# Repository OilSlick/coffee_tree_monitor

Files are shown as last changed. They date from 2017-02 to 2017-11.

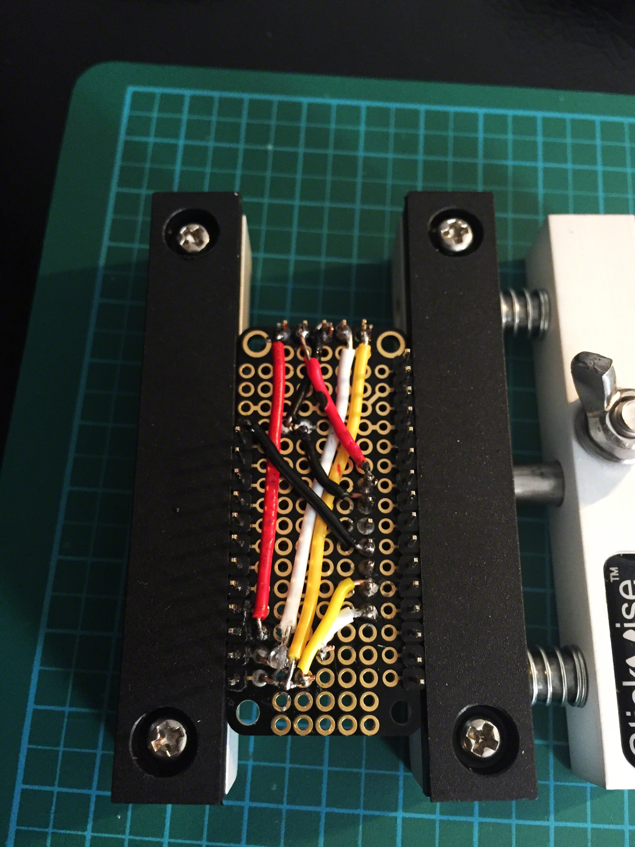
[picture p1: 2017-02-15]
images/proto-back.jpg

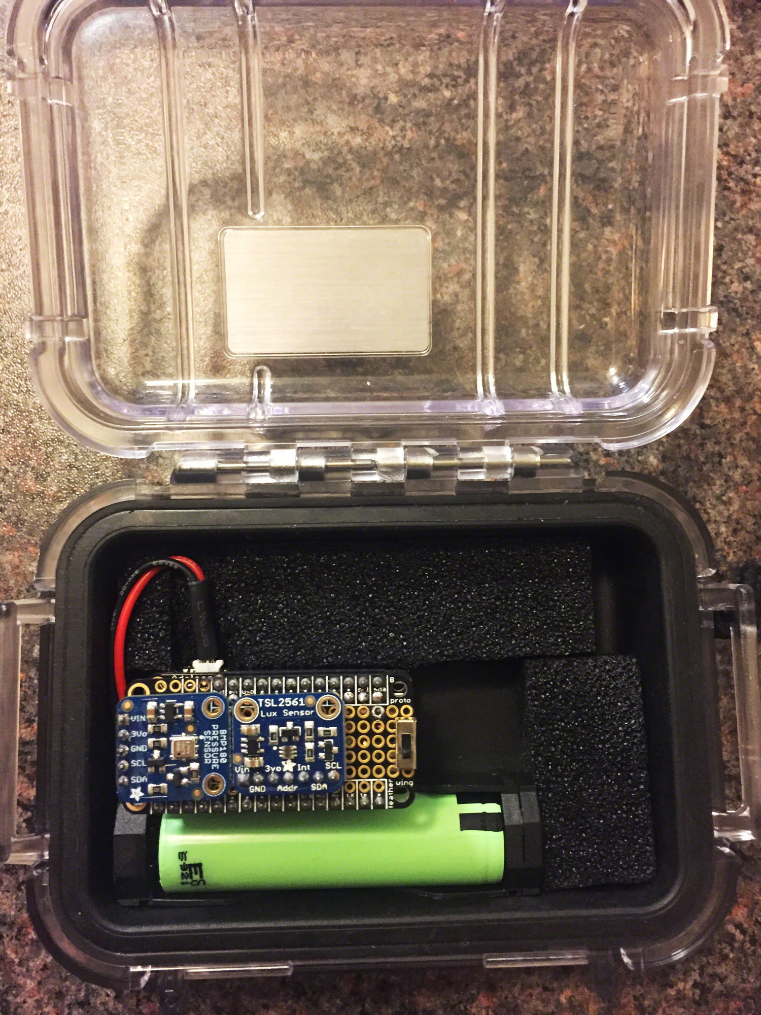
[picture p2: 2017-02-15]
images/sensor-case.jpg

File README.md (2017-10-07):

# Coffee Tree Monitor
An Arduino-based sensor network to monitor environmental conditions of coffee trees.

Intended to compare the differences between two types of microclimate for coffee trees; shaded and unshaded environments. 

### Basic Unit Operation

Collect the following data from each tree:

1. Amount of light
2. Air temperature
3. Soil moisture content 

**As of October 7, 2017 this project is still being developed.** I am currently prototyping the circuit and all of the sensors, which I'm still researching and sourcing.  

Current unit configurations and tests are being documented in the [wiki](https://github.com/OilSlick/coffee_tree_monitor/wiki)

### Hardware To-Do
* [x] Add SD Card adapter
* [ ] Add soil sensor
* [x] Add light sensor
* [x] Add solar panel 
* [x] Determine method for posting data online
* [ ] Organize circuit for project/gang box
* [ ] Evaluate battery life and consider physically smaller LiPo to replace current Li-ion battery

### Software To-Do
* [x] Configure for SD Card adapter
* [x] Add lowpower/sleep routines
* [x] Power down sensors between data collection ~~(this is causing problems with TSL2561)~~
* [ ] Configure Fona routines for data upload
* [ ] Add error handling and logging to SD, www, and via LED blink
  * [ ] ~~Add error on bmp.getTemperature~~
  * [x] Skip Adafruit IO conn attempt if wifi fails
  * [x] Fix failure to detect TSL2561 init fail
* [ ] Rotate log files

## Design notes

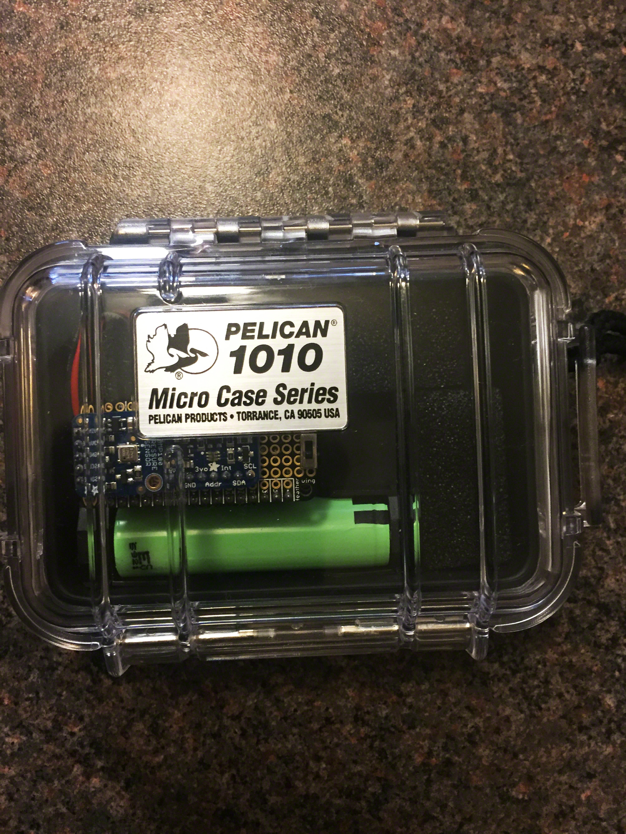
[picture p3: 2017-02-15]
images/sensor-case2.jpg

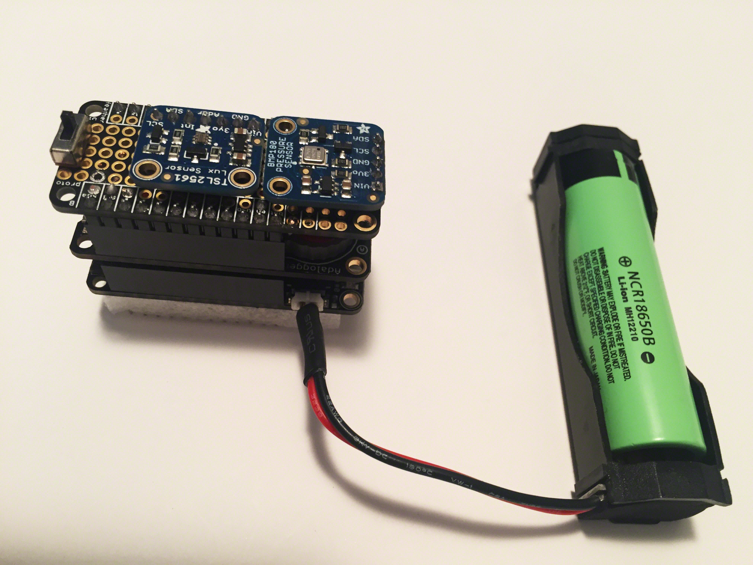
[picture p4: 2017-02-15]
images/sensor-batt2.jpg

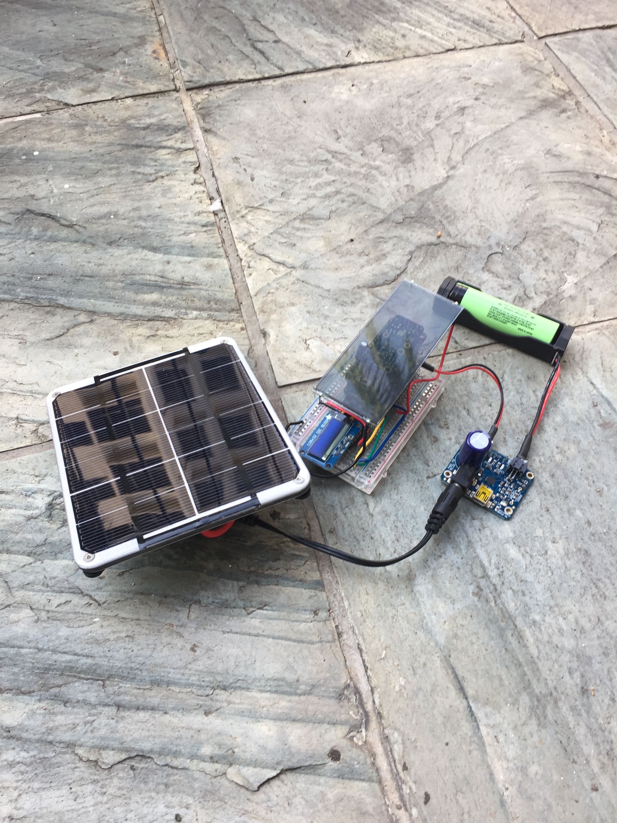
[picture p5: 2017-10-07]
images/solar-powered.jpg

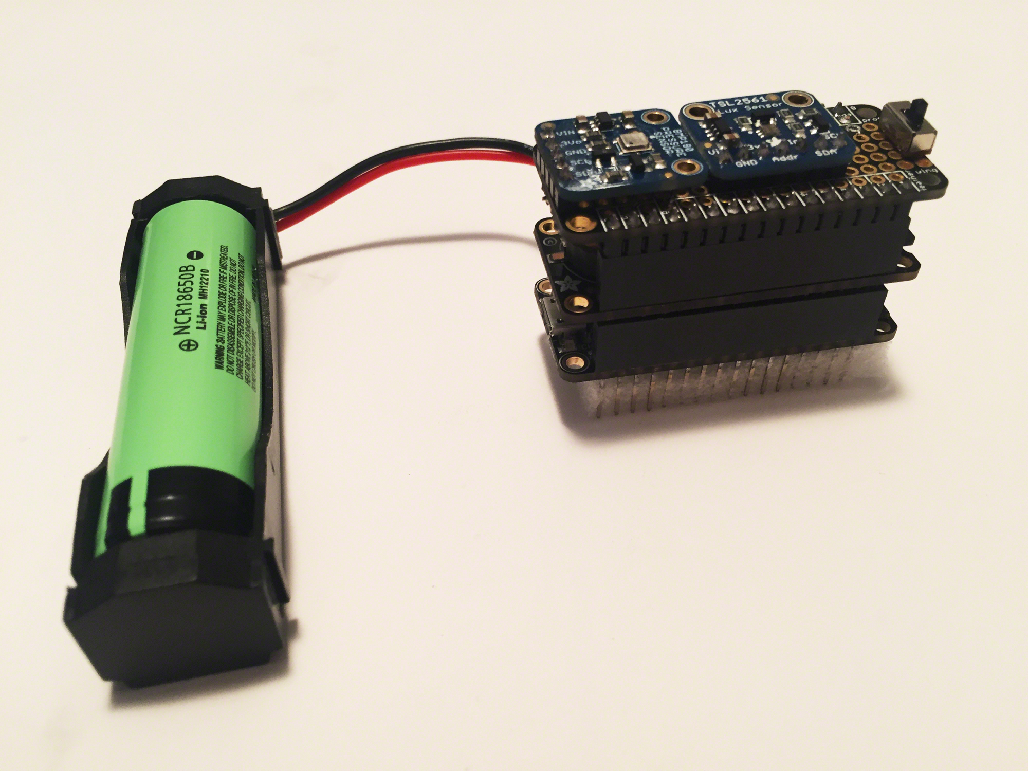
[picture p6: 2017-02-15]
images/sensor-batt.jpg

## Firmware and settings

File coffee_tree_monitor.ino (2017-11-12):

#include <Wire.h>                     //Needed for I2C 
#include <Adafruit_Sensor.h>          //Needed for both BMP180 and TSL2561
#include <SPI.h>                      //Needed for SD card adapter
#include <SD.h>                       //Needed for SD card adapter
#include "config.h"                   //Needed for Adafruit IO

//For OLED display
#include <Adafruit_GFX.h>
#include <Adafruit_SSD1306.h>
#define OLED_RESET 0
Adafruit_SSD1306 display(OLED_RESET);

/* I2C addresses:
   0x29  (41) TSL2561 Lux sensor
   0x3C       OLED Display
   0x68 (104) RTC
   0x77 (119) BMP180 Baro sensor
*/

String Statuses[] =  { "WL_IDLE_STATUS=0", "WL_NO_SSID_AVAIL=1", "WL_SCAN_COMPLETED=2", "WL_CONNECTED=3", "WL_CONNECT_FAILED=4", "WL_CONNECTION_LOST=5", "WL_DISCONNECTED=6"};
String TimeStamp = "";                //String to contain the timestamp for log files

const int SenorPowerPin = 2;          //Pin used to provide power to sensors
const int chipSelect = 15;            //CS pin for SD card adapter
const int lclvPin = 16;               //Controls the LCLV glass

const int TSL2561I2CAdd = 41;         //I2C address of TSL2561 (found using I2C sketch)
const int BMP180I2CAdd = 119;         //I2C address of BMP180 (found using I2C sketch)
bool IOconnERROR = 0;                 //Track connection failures
bool debug = 0;                       //Enable debugging with "1"
bool JustPrintRuntimeOnce = 0;        //Just give us one runtime reading
bool LCLVactive = 0;                  //Track if LCLV is on or off
int LCLVValue = 0;                    //Track LCLV value
float PressureVal = 0;                //Value returned by sensor
float TSL2561Val = 0;                 //Value returned by sensor
float TemperatureVal = 0;             //Value returned by sensor
bool BMP180Error = 0;                 //Track sensor errors
bool TSL2561Error = 0;                //Track sensor errors
bool SDError = 0;                     //Track SD adapter errors
bool WiFiError = 0;                   //Track WiFi connection error
byte I2Cerror;                        //Track I2C errors (when pinging individual addresses for up/down status)
int StartLoopRuntime;                 //Track loop run time (enabled with "debug = 1;" above)
int LoopRuntime;                      //Track loop run time (enabled with "debug = 1;" above)

int ThisSecond = 0;                   //Used to display on OLED for short duration
int DisplayDuration = ThisSecond + 10;  //Used to display on OLED for short duration

//For Adafruit IO
AdafruitIO_Feed *luxFeed = io.feed("Lux");
AdafruitIO_Feed *tempFeed = io.feed("Temp");
AdafruitIO_Feed *presFeed = io.feed("Pressure");
AdafruitIO_Feed *errorFeed = io.feed("Error");

//For SD card adapter
File DATALOG;
File ERRORLOG;
File LUXLOG;

//For BMP180 pressure, temp, altitude sensor
#include <Adafruit_BMP085_U.h>
Adafruit_BMP085_Unified bmp = Adafruit_BMP085_Unified(10085);

//For RTC
#include "RTClib.h"
RTC_PCF8523 rtc;

//For Lux sensor
#include <Adafruit_TSL2561_U.h>
Adafruit_TSL2561_Unified tsl = Adafruit_TSL2561_Unified(TSL2561_ADDR_LOW, 2561);

void setup()
{
  wdt_enable(WDTO_4S);  //Configure watchdog timer with 4-second timeout

  //For OLED display
  display.begin(SSD1306_SWITCHCAPVCC, 0x3C);  // initialize with the I2C addr 0x3C (for the 128x32)
  display.clearDisplay();
  display.display(); // NOTE: You _must_ call display after making any drawing commands

  rtc.begin();

  //Power on sensors early in loop
  pinMode(SenorPowerPin, OUTPUT);
  digitalWrite(SenorPowerPin, HIGH);

  pinMode(lclvPin, OUTPUT);
  analogWrite(lclvPin, 0);

  Serial.begin(115200);
  if ( debug == 1)
  {
    Serial.setDebugOutput(true);
    if ( Serial )
    {
      Serial.print("Debug enabled");
    }
  }

  Wire.begin();

  //For SD card adapter
  Serial.print("Initializing SD card...");
  pinMode(SS, OUTPUT);

  if (!SD.begin(chipSelect)) {
    Serial.println("SD card initialization failed");
    SDError = 1;
    //return;  //Need to better handle this error
  }
  else
  {
    Serial.println("SD card initialization done");
  }

  DATALOG = SD.open("log.txt", FILE_WRITE);
  // if the file opened, write header to it:
  if (DATALOG)
  {
    DATALOG.println("Date Time,Lux,Temp.C,Pressure.hPa");
    DATALOG.close();
  }
  else
  {
    // if the file didn't open, print an error to serial:
    if (Serial)
    {
      Serial.println("Error opening data log file");
    }
  }

  ERRORLOG = SD.open("error.txt", FILE_WRITE);
  // if the file opened, write header to it:
  if (ERRORLOG)
  {
    ERRORLOG.println("Date Time,Error");
    ERRORLOG.close();
  }
  else
  {
    // if the file didn't open, print an error:
    if (Serial)
    {
      Serial.println("Error opening error log file");
    }
  }

  //For BMP180
  if (Serial)
  {
    Serial.println("Initilizing Pressure Sensor"); Serial.println("");
  }

  /* Initialise the sensor */

  if (!bmp.begin())
  {
    /* There was a problem detecting the BMP085 ... check your connections */
    if (Serial)
    {
      Serial.println("No BMP180 detected ... Check your wiring or I2C address");
    }
    ERRORLOG = SD.open("error.txt", FILE_WRITE);
    if (ERRORLOG)
    {
      TimeStampSD(ERRORLOG);
      ERRORLOG.print("BMP180 is not responding");
      ERRORLOG.close();
    }
    BMP180Error = 1;
  }

  /* Display some basic information on this sensor */
  displayBMP180SensorDetails();

  //For TSL2561 sensor

  if (Serial)
  {
    Serial.println("Initilizing Light Sensor"); Serial.println("");
  }

  /* Initialise the sensor */

  Wire.beginTransmission(TSL2561I2CAdd);
  I2Cerror = Wire.endTransmission();
  if (Serial && debug == 1)
  {
    Serial.print("TSL2561 I2C error: ");
    Serial.println(I2Cerror);
  }
  if ( I2Cerror != 0 )  //Error "0" indicates a successful contact
  {
    if (Serial)
    {
      Serial.print("TSL2561 is not responding at address: ");
      Serial.print(TSL2561I2CAdd);
      Serial.print(" ("); Serial.print(TSL2561I2CAdd, HEX); Serial.println(")");
    }

    ERRORLOG = SD.open("error.txt", FILE_WRITE);
    if (ERRORLOG)
    {
      TimeStampSD(ERRORLOG);
      ERRORLOG.print("TSL2561 is not responding at address: ");
      ERRORLOG.print(TSL2561I2CAdd);
      ERRORLOG.print("(0x"); ERRORLOG.print(TSL2561I2CAdd, HEX); ERRORLOG.println(")");
      ERRORLOG.close();
      TSL2561Error = 1;
    }
  }

  if (!tsl.begin())
  {
    /* There was a problem detecting the TSL2561 ... check your connections */
    if (Serial)
    {
      Serial.println("No TSL2561 detected ... Check your wiring or I2C address");
    }
    TSL2561Error = 1;
  }

  /* Display some basic information on this sensor */
  displayTSL2561SensorDetails();

  /* Setup the sensor gain and integration time */
  configureSensor();

  //For RTC (must occur late in the loop)
  //Uncomment the line below to set the RTC
  if ( Serial )
  {
    //rtc.adjust(DateTime(F(__DATE__), F(__TIME__)));
  }

  //Connect to WiFi
  wdt_reset();
  Connect();

  //Connect to Adafruit IO
  if ( WiFiError == 0)
  {
    Serial.println("Connecting to Adafruit IO");
    // connect to io.adafruit.com
    // io.connect();
    // attach message handler for the each feed
    wdt_reset();
    luxFeed->onMessage(handleMessage);
    tempFeed->onMessage(handleMessage);
    presFeed->onMessage(handleMessage);
    errorFeed->onMessage(handleMessage);

    // wait for a connection
    int IOconnAttempt = 0;
    while (io.status() < AIO_CONNECTED && IOconnAttempt <= 60)
    {
      Serial.print(".");
      delay(500);
      IOconnAttempt++;
    }
    if ( IOconnAttempt > 60 )
    {
      IOconnERROR = 1;
      if ( Serial )
      {
        Serial.println("");
        Serial.println("Aborting connection attempt to Adafruit IO");
        Serial.print("IP address:   ");
        Serial.println(WiFi.localIP());
      }
      ERRORLOG = SD.open("error.txt", FILE_WRITE);
      if (ERRORLOG)
      {
        TimeStampSD(ERRORLOG);
        ERRORLOG.println("Adafruit IO connection failed");
        ERRORLOG.close();
      }
    }
    IOconnAttempt = 0;

    // we are connected
    if ( Serial );
    {
      Serial.println();
      Serial.println(io.statusText());
    }
  }
  if ( IOconnERROR == 0 && WiFiError == 0 && TSL2561Error == 0 && BMP180Error == 0 && SDError == 0 )
  {
    ERRORLOG = SD.open("error.txt", FILE_WRITE);
    TimeStampSD(ERRORLOG);
    ERRORLOG.println("REBOOT: OK");
    ERRORLOG.close();
    errorFeed->save("REBOOT: OK");
  }

  if ( IOconnERROR == 0 )
  {
    if ( BMP180Error == 1 )
    {
      errorFeed->save("REBOOT: BMP180 error");
    }
    if ( TSL2561Error == 1 )
    {
      errorFeed->save("REBOOT: TSL2561 error");
    }
    if ( SDError == 1 )
    {
      errorFeed->save("REBOOT: SD card error");
    }
  }

  LUXLOG = SD.open("luxlog.txt", FILE_WRITE);
  if (LUXLOG )
  {
    LUXLOG.println("Date Time,LCLV Raw,LCLV Modified,LCLV Value");
    LUXLOG.close();
  }

  if ( Serial )
  {
    /* We're ready to go! */
    Serial.println("Beginning data collection");
    //For OLED display
    display.clearDisplay();
    display.setTextSize(1);
    display.setTextColor(WHITE);
    display.setCursor(10, 0);
    display.print("Ready");
    display.display();    // NOTE: You _must_ call display after making any drawing commands
    delay(2500);
    display.clearDisplay();
    display.display();
  }
}

void loop()
{
  DateTime now = rtc.now();

  if ( debug == 1 )
  {
    StartLoopRuntime = millis();
    analogWrite(lclvPin, 1023);
    ReadTSL2561();
    //For OLED display
    display.clearDisplay();
    display.setTextSize(1);
    display.setTextColor(WHITE);
    display.setCursor(10, 0);
    display.print(TSL2561Val);
    display.display();    // NOTE: You _must_ call display after making any drawing commands
    /*LUXLOG = SD.open("luxlog.txt", FILE_WRITE);
      if (LUXLOG )
      {
      TimeStampSD(LUXLOG);
      LUXLOG.print(TSL2561Val);
      LUXLOG.print(",");
      LUXLOG.close();
      } */
    delay(2000);

    analogWrite(lclvPin, 511);
    ReadTSL2561();
    //For OLED display
    display.clearDisplay();
    display.setTextSize(1);
    display.setTextColor(WHITE);
    display.setCursor(10, 0);
    display.print(TSL2561Val);
    display.display();    // NOTE: You _must_ call display after making any drawing commands
    /*LUXLOG = SD.open("luxlog.txt", FILE_WRITE);
      if (LUXLOG )
      {
      TimeStampSD(LUXLOG);
      LUXLOG.print(TSL2561Val);
      LUXLOG.print(",");
      LUXLOG.close();
      }*/
    delay(2000);

    analogWrite(lclvPin, 0);
    ReadTSL2561();
    //For OLED display
    display.clearDisplay();
    display.setTextSize(1);
    display.setTextColor(WHITE);
    display.setCursor(0, 0);
    display.print(TSL2561Val);
    display.display();    // NOTE: You _must_ call display after making any drawing commands
    /*LUXLOG = SD.open("luxlog.txt", FILE_WRITE);
      if (LUXLOG )
      {
      LUXLOG.println(TSL2561Val);
      LUXLOG.close();
      }*/
    //delay(2000);
  }

  //Clear display after 15s
  if ( now.second() >= DisplayDuration )
  {
    display.clearDisplay();
    display.display();
  }
  // io.run(); keeps the client connected to
  // io.adafruit.com, and processes any incoming data.
  if ( WiFiError == 0 && IOconnERROR == 0 )
  {
    io.run();
  }

  if ( now.second() == 0 ) //Update SD log file every minute
  {
    if ( LCLVactive == 1 )
    {
      //shut off LCLV to get good read on LUX
      analogWrite(lclvPin, 0);
      LCLVactive = 0;
    }
    if ( BMP180Error == 0 )
    {
      ReadBMP180();
    }
    if ( TSL2561Error == 0 )
    {
      ReadTSL2561();
    }
    LUXLOG = SD.open("luxlog.txt", FILE_WRITE);
    if (LUXLOG )
    {
      TimeStampSD(LUXLOG);
      LUXLOG.print(TSL2561Val);
      LUXLOG.print(",");
      LUXLOG.close();
    }
    // If lux is nearing saturation, utlize LCLV and take a new reading
    if ( TSL2561Val >= 10000 )
    {
      LCLVValue = 859;  //LCLV at 859; 84% of 3v which is 50% at 5v, the voltage of LCLV
      analogWrite(lclvPin, LCLVValue);
      LCLVactive = 1;
      ReadTSL2561();
      analogWrite(lclvPin, 0); //Turn off LCLV to save juice
      LCLVactive = 0;
      LUXLOG = SD.open("luxlog.txt", FILE_WRITE);
      if (LUXLOG )
      {
        LUXLOG.print(TSL2561Val);
        LUXLOG.print(",");
        LUXLOG.println(LCLVValue);
        LUXLOG.close();
      }
    }
    else
    {
      LUXLOG = SD.open("luxlog.txt", FILE_WRITE);
      if (LUXLOG )
      {
        LUXLOG.print("0");
        LUXLOG.print(",");
        LUXLOG.println("0");
        LUXLOG.close();
      }
    }
    if ( Serial )
    {
      Serial.print(now.hour(), DEC);
      Serial.print(":");
      Serial.print(now.minute(), DEC);
      Serial.print(":");
      Serial.println(now.second(), DEC);
      WriteBMP180Serial();
      WriteTSL2561Serial();
      ThisSecond = now.second();
      DisplayDuration = ThisSecond + 15;
      WriteBMP180OLED();
      WriteTSL2561OLED();
      display.setTextSize(1); //textsize 1 = 7 px high
      display.setTextColor(WHITE);
      display.setCursor(50, 24);
      display.print(now.hour(), DEC);
      display.print(":");
      display.print(now.minute(), DEC);
      display.print(":");
      display.println(now.second(), DEC);
      display.display();
    }
    DATALOG = SD.open("log.txt", FILE_WRITE);
    // if the file opened okay, write to it:
    if (DATALOG)
    {
      TimeStampSD(DATALOG);
      if ( TSL2561Error == 0 )
      {
        WriteTSL2561SD();
      }
      if ( BMP180Error == 0 )
      {
        WriteBMP180SD();
      }
      DATALOG.println();
      DATALOG.close();
    }
    else
    {
      // if the file didn't open, print an error:
      Serial.println("error opening log file");
    }
    if (WiFiError == 0 && IOconnERROR == 0 )
    {
      if ( BMP180Error == 0 )
      {
        wdt_reset();
        WriteBMP180IO();
      }
      if ( TSL2561Error == 0 )
      {
        wdt_reset();
        WriteTSL2561IO();
      }
    }
    else
    {
      if ( Serial )
      {
        Serial.println("Not attempting write to Adafruit IO (IOConnERROR = 1)");
      }
    }
  }

  if ( debug == 1)
  {
    if ( now.second() == 0 || now.second() == 30 && JustPrintRuntimeOnce == 0 )
    {
      LoopRuntime = (millis() - StartLoopRuntime);
      Serial.print("Loop runtime: "); Serial.print(LoopRuntime); Serial.println(" ms");
      JustPrintRuntimeOnce = 1;
    }
    else
    {
      JustPrintRuntimeOnce == 0;
    }
  }
}

void TimeStampSD(File LogFile)  //Requires the name of the logfile to be passed, i.e. TimeStampSD(ERRORLOG);
{
  DateTime now = rtc.now();

  String theyear = String(now.year(), DEC);
  String themonth = String(now.month(), DEC);
  String theday = String(now.day(), DEC);
  String thehour = String(now.hour(), DEC);
  String themin = String(now.minute(), DEC);
  //Put all the time and date strings into one String
  TimeStamp = String(theyear + "/" + themonth + "/" + theday + " " + thehour + ":" + themin + ",");

  LogFile.print(TimeStamp);
}

void Connect()
{
  if ( WiFiError == 0 )
  {
    if (Serial)
    {
      Serial.print("Connecting to ");
      Serial.println(WIFI_SSID);
    }

    if (WiFi.status() != WL_CONNECTED)
    {
      WiFi.begin(WIFI_SSID, WIFI_PASS);
      int Attempt = 0;
      while (WiFi.status() != WL_CONNECTED)
      {
        delay(500);
        Attempt++;
        Serial.print(".");
        if (Attempt == 60)
        {
          if (Serial)
          {
            Serial.println();
            Serial.println("WiFi connection failed");
          }
          ERRORLOG = SD.open("error.txt", FILE_WRITE);
          if (ERRORLOG)
          {
            TimeStampSD(ERRORLOG);
            ERRORLOG.println("WiFi connection failed");
            ERRORLOG.close();
          }
          WiFiError = 1;
          IOconnERROR = 1; //If no WiFi connection, prevent connection to Adafruit IO
          return;
        }
      }
    }
    Serial.println("");
    Serial.println("WiFi connected");
    Serial.print("IP address: ");
    Serial.println(WiFi.localIP());
  }
}

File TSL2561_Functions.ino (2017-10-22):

void displayTSL2561SensorDetails(void)
{
  sensor_t sensor;
  tsl.getSensor(&sensor);
  Serial.println("------------------------------------");
  Serial.print  ("Sensor:       "); Serial.println(sensor.name);
  Serial.print  ("Driver Ver:   "); Serial.println(sensor.version);
  Serial.print  ("Unique ID:    "); Serial.println(sensor.sensor_id);
  Serial.print  ("Max Value:    "); Serial.print(sensor.max_value); Serial.println(" lux");
  Serial.print  ("Min Value:    "); Serial.print(sensor.min_value); Serial.println(" lux");
  Serial.print  ("Resolution:   "); Serial.print(sensor.resolution); Serial.println(" lux");  
  Serial.println("------------------------------------");
  delay(500);
}

/**************************************************************************/
/*
    Configures the gain and integration time for the TSL2561
*/
/**************************************************************************/
void configureSensor(void)
{
  /* You can also manually set the gain or enable auto-gain support */
   tsl.setGain(TSL2561_GAIN_1X);      /* No gain ... use in bright light to avoid sensor saturation */
  // tsl.setGain(TSL2561_GAIN_16X);     /* 16x gain ... use in low light to boost sensitivity */
  // tsl.enableAutoRange(true);            /* Auto-gain ... switches automatically between 1x and 16x */
  
  /* Changing the integration time gives you better sensor resolution (402ms = 16-bit data) */
  // tsl.setIntegrationTime(TSL2561_INTEGRATIONTIME_13MS);      /* fast but low resolution */
  // tsl.setIntegrationTime(TSL2561_INTEGRATIONTIME_101MS);  /* medium resolution and speed   */
   tsl.setIntegrationTime(TSL2561_INTEGRATIONTIME_402MS);  /* 16-bit data but slowest conversions */

  /* Update these values depending on what you've set above! 
  Serial.print  ("Gain:         "); Serial.println("Auto");
  Serial.print  ("Timing:       "); Serial.println("402 ms");
  Serial.println("------------------------------------"); */
}

void ReadTSL2561()
{
  /* Get a new sensor event */ 
  sensors_event_t event;
  tsl.getEvent(&event);   //TSL2561 Lux sensor
  
  /* Display the results (light is measured in lux) */
  if (event.light)
  {
    TSL2561Val = event.light;
    if ( TSL2561Val >= 17000 )
    {
      errorFeed->save("TSL2561 sensor saturated");  //Log error to Adafruit IO
      ERRORLOG = SD.open("error.txt", FILE_WRITE);
      if (ERRORLOG)
    {
      TimeStampSD(ERRORLOG);
      ERRORLOG.println("TSL2561 Sensor Error: lux above sensor max threshold");
      ERRORLOG.close();
    }
    }
  }
  else
  {
    /* If event.light = 0 lux during sun-down, there is likely not enough light for the sensor to read */
    TSL2561Val = 0;
  }  
}

void WriteTSL2561Serial()
{
  Serial.print("Lux:         ");
  Serial.print(TSL2561Val);
  Serial.println(" Lux");
}

void WriteTSL2561SD()
{
  DATALOG.print(TSL2561Val);
  DATALOG.print(",");
}

void WriteTSL2561IO()
{
  luxFeed->save(TSL2561Val);
}

void WriteTSL2561OLED()
{
  display.setTextSize(1); //textsize 1 = 7 px high
  display.setTextColor(WHITE);
  display.setCursor(0,16);
  display.print("Lux:      ");
  display.print(TSL2561Val);
  display.println(" Lux");
  display.display();    // NOTE: You _must_ call display after making any drawing commands
}

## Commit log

2017-01-26 Updated docs
    [coffee_tree_monitor.fzz]
2017-02-02 Several changes
    including low power implementation and SD card utilization (memory hog).
    [coffee_tree_monitor.fzz]
2017-02-03 Added delays around TSL2561 re-inits
    Adding 500ms delays after power-up and again after re-initialization
    and configuration seem to correct the issue with incorrect lux readings
    after powering off the sensor.
    [TSL2561_Functions.ino, coffee_tree_monitor.ino]
2017-02-03 Blink onboard LED to signal end of startup
2017-02-03 Updated to include SD adapter
    [coffee_tree_monitor.fzz]
2017-02-07 Updated schematics and a test sketch
    [coffee_tree_monitor.fzz]
2017-02-08 Update files with huzzah code
    Archived sketches based on the Fona and replaced with current sketches
    based on the Huzzah
    [BMP180_Functions.ino, TSL2561_Functions.ino, adafruit_io_functions.ino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]
2017-02-08 changed error syntax and to-do
    [BMP180_Functions.ino, coffee_tree_monitor.ino]
2017-02-09 toned down error messages, renamed fritzing diagram
    [coffee_tree_monitor_fona_dev.fzz]
2017-02-10 rename all functions to match naming conventions
    action, sensor, target
2017-02-14 Several offline changes (mostly error handling)
    [BMP180_Functions.ino, TSL2561_Functions.ino, adafruit_io_functions.ino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]
2017-02-15 Writing to wrong log file
    [coffee_tree_monitor.ino]
2017-02-15 Report errors to Adafruit IO
    [TSL2561_Functions.ino, coffee_tree_monitor.ino]
2017-02-16 stop passing error to function
    Just don't call function during error state
    [BMP180_Functions.ino, TSL2561_Functions.ino, coffee_tree_monitor.ino]
2017-02-16 Don't log values if sensor error
    [coffee_tree_monitor.ino]
2017-02-16 Log reboots to error log
    [coffee_tree_monitor.ino]
2017-02-16 Track and report SD Card errors
    [coffee_tree_monitor.ino]
2017-02-17 Configure and utilize wdt
    watchdog timer
2017-02-17 move initial error reporting to setup()
    [coffee_tree_monitor.ino]
2017-02-17 corrected order in which values are written to SD
    [coffee_tree_monitor.ino]
2017-02-18 Log BMP180 errors to SD
    [coffee_tree_monitor.ino]
2017-04-25 Good LCLV test
    esp8266 PWM resolution is 0-1023, not 0-255 like Uno
2017-10-06 Display on OLED for short duration
    [coffee_tree_monitor.ino]
2017-10-06 reduce text size to reduce power consumption
2017-10-07 implemented dynamic LCLV usage
    take LUX reading and if >= 10000 Lux, utilize LCLV and take another
    reading to be recorded. Only one adjustment currently. I am hoping at
    50% of LCLV, the TSL2561 won't be saturated.
    [coffee_tree_monitor.ino]
2017-10-22 changed TSL2561 gain
    The sensor's current maximum reading seems to be 14184. Trying to get
    better resolution.
